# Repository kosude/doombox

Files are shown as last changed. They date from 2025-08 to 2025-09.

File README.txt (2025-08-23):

This repository contains all documentation and code for the DOOMbox Project.

My final goal for this project is an encased physical console, based on the
Pico 2 (RP2350 using Arm) dedicated to running a purpose-built DOOM clone,
maybe with a bunch of extra features thrown in for fun.

This is an evolution of my previous ambition to write a functional DOOM clone
in pure x86 assembly. The software for DOOMbox will instead be written in a
combination of C and assembly. The old project is below:

    https://gitlab.com/kosude/doom

It should be noted that Graham Saunderson has done something similar:

    https://kilograham.github.io/rp2040-doom

To be clear, DOOMbox was not inspired by RP2040 Doom, though his documentation
will probably be very helpful going forward, as I will be using similar
hardware. The main difference is that this project is more intended to just be
a fun learning experience as opposed to trying to make an authentic DOOM port
(which is why I'm not porting at all).

-------------------------[ BUILDING DOOMBOX FIRMWARE ]-------------------------

Building the firmware requires CMake, as well as the pico-sdk:

    https://github.com/raspberrypi/pico-sdk

Then (in the root project directory) configure for the desired build type:
    $ cmake . -Bbuild -DCMAKE_BUILD_TYPE=(Debug|Release)
and build:
    $ cmake --build build

Using the Debug build type enables stdio logging, which can help in debugging
(see the relevant section below).

Make sure the DBX_BUILD_FIRMWARE build option is set to ON - this is the
default value.

------------------------[ DEBUGGING DOOMBOX FIRMWARE ]-------------------------

Raspberry Pi document how to debug Pico software in one of their manuals:

    https://datasheets.raspberrypi.com/pico/getting-started-with-pico.pdf

There are multiple ways to debug, but the only properly tested route for
DOOMbox is with a second Pico, since it's the best way IMO and I don't want to
buy a "debug probe".

To go that route, GDB is required as well as Raspberry Pi's OpenOCD fork:

    https://github.com/raspberrypi/openocd

Program and set up the second Pico as shown in the Getting Started guide above
(I use the official debugprobe firmware) and then connect it to the host via
USB.

The rest of the process can be done for you by the Unified Programming and
Debugging Utility (updu.sh) in the scripts/ directory, which will by default
open a GDB session for debugging.

Reading stdout can be done in any standard way. For instance, using minicom
with a second Pico, run:

    $ minicom -b 115200 -o -D /dev/ttyACM0

(of course the device might be different)

###############################################################################

The rest of this document serves as the project's most current design
specification. Kicad schematics are also provided in the hardware/ directory.

-------------------------------[ PREREQUISITES ]-------------------------------

    ==== UNITS ====

The design specification will follow IEC 80000-13 (B: byte, b: bit):
    * 1 B   = 8 b
    * 1 kiB = 1024 B
    * 1 kB  = 1000 B
    * etc...
In all cases, use of the standard SI units indicates a decimal value, whereas
use of the IEC 80000-13 units indicates a binary value.

-----------------------------[ FILESYSTEM LAYOUT ]-----------------------------

Available capacity:
    * 4 MiB on-board flash/NVM

--------------------------------[ MEMORY MAP ]---------------------------------

TO-DO: specify memory map after reserved quantities are designated

Available memory:
    * 512 kiB on-chip SRAM
    * 2 x 4 kiB banks

Reserved memory quantities:
    * 128 kB for VGA output (320x200, 8 bpp):
        64 kB front buffer
        64 kB back buffer

----------------------------[ POWER SPECIFICATION ]----------------------------

For the time being, a simple LDO regulator is being used to step down input
voltage to 5V.

---------------------------[ GRAPHICS SPECIFICATION ]--------------------------

DOOMbox provides graphical output via VGA. Colour data is output in parallel
from the Pico directly to the VGA connector.

Colour data is output in the form RGB-332, i.e. 3 bits for the red and green
channels, and 2 for the blue.

On the Pico, GPIOs 2-9 are reserved for video data and and 10-11 for HSync and
VSync signals respectively.

When writing colour data serially, the bit-order is as follows:
    B1 B0 G2 G1 G0 R2 R1 R0
  first ---------------> last
where the leftmost bit of each channel is the MSB as usual.

Time-critical PIO machines are used for producing the synchronisation signals.
For detailed VGA timing information, see the TIMINGS.txt file in the
firmware/kernel/drivers/vga/ directory.

----------------------------[ AUDIO SPECIFICATION ]----------------------------

Stereo audio is provided via pulse width modulation (PWM). GPIOs 8 and 9 are
reserved for this purpose, where GPIO8 outputs left audio, and GPIO9 right.

    TODO better description

----------------------------[ INPUT SPECIFICATION ]----------------------------

    TODO

Required controls:
    * Move forward + move backwards | Single joystick: vertical: moving
    * Turn left + turn right        |                  horizontal: turning
    * Strafe                          Modifier btn: strafe with hoz. joystick
    * Run / speed modifier            Modifier button
    * Fire                            Button
    * Interact                        Button
    * Menu                            Button
    * Weapon selection                7 buttons

Automap necessary?

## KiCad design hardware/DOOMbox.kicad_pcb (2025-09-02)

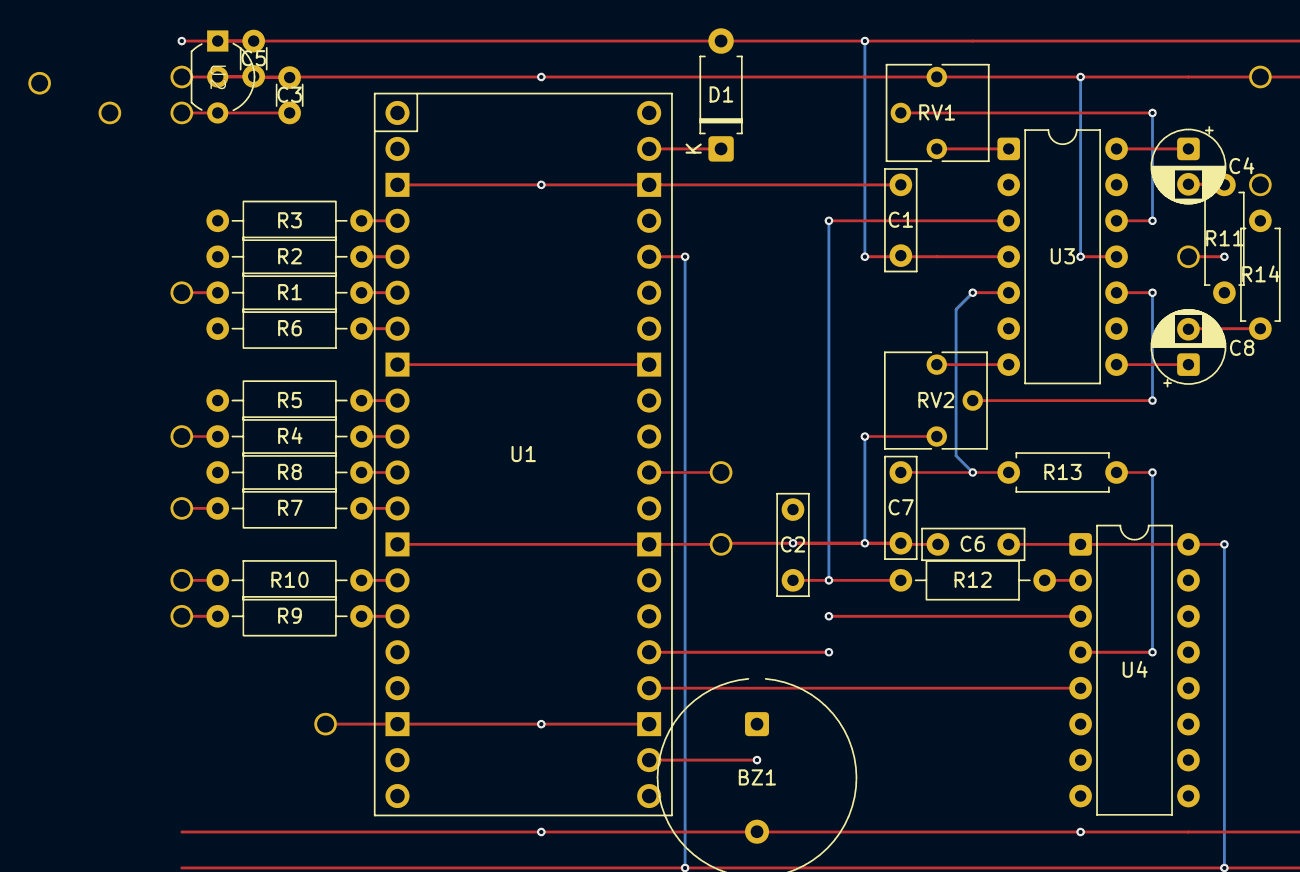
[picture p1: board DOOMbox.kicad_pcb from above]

Board: 4 copper layers, 43 parts (0 on the bottom side), 38 nets.

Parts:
BZ1: Buzzer; Indicator_PUI_AI-1440-TWT-24V-2-R
C1, C6: 100n; C_Rect_L7.0mm_W2.0mm_P5.00mm
C2, C7: 8n2; C_Rect_L7.0mm_W2.0mm_P5.00mm
C3: 1u; C_Disc_D3.0mm_W1.6mm_P2.50mm
C4, C8: 4u7; CP_Radial_D5.0mm_P2.50mm
C5: 2u2; C_Disc_D3.0mm_W1.6mm_P2.50mm
D1: D; D_A-405_P7.62mm_Horizontal
J1, J1#2, J1#3, J1#4, J1#5, J1#6: DE15_Socket_HighDensity; Peripheral_Offboard
J2, J2#2, J2#3: AudioJack3; Peripheral_Offboard
R1, R4: 499R; R_Axial_DIN0207_L6.3mm_D2.5mm_P10.16mm_Horizontal
R2, R5: 1K; R_Axial_DIN0207_L6.3mm_D2.5mm_P10.16mm_Horizontal
R3, R6: 2K; R_Axial_DIN0207_L6.3mm_D2.5mm_P10.16mm_Horizontal
R7: 412R; R_Axial_DIN0207_L6.3mm_D2.5mm_P10.16mm_Horizontal
R8, R12: 826R; R_Axial_DIN0207_L6.3mm_D2.5mm_P10.16mm_Horizontal
R9, R10: 47R; R_Axial_DIN0207_L6.3mm_D2.5mm_P10.16mm_Horizontal
R11, R14: 10K; R_Axial_DIN0207_L6.3mm_D2.5mm_P7.62mm_Horizontal
R13: 826R; R_Axial_DIN0207_L6.3mm_D2.5mm_P7.62mm_Horizontal
RV1, RV2: 100K; Potentiometer_Vishay_T73YP_Vertical
SW1, SW1#2, SW1#3: SW_SPST; Peripheral_Offboard
SW2: SW_Push; Peripheral_Offboard
U1: RPi Pico 2; RPi_Pico_SMD_TH
U2: AP7381-50SA-7; AP7381-TO92
U3: LM324N; DIP-14_W7.62mm
U4: CD4010BE; DIP-16_W7.62mm

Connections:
+3V3: C6.1, U1.36 (3V3), U4.1 (VCC), U4.16 (VDD)
+5V: C1.1, C5.1, D1.2 (A), U2.1 (VI), U3.4 (V+)
GND: BZ1.2 (-), C1.2, C2.2, C3.2, C5.2, C6.2, C7.2, J1#6.VGAGND, J2#2.S, RV1.1, RV2.1, U1.3 (GND), U1.8 (GND), U1.13 (GND), U1.18 (GND), U1.23 (GND), U1.28 (GND), U1.33 (AGND), U1.38 (GND), U2.2 (VO), U3.11 (V-), U4.8 (VSS)
HSYNC: R10.2, U1.14 (GPIO10)
unnamed: BZ1.1 (+), U1.22 (GPIO17)
unnamed: C4.2, R11.1
unnamed: C8.2, R14.1
unnamed: D1.1 (K), U1.39 (VSYS)
unnamed: J1#3.VGA1, R1.2, R2.2, R3.2
unnamed: J1#5.VGA2, R4.2, R5.2, R6.2
unnamed: J1.VGA3, R7.2, R8.2
unnamed: J1#4.VGA13, R10.1
unnamed: J1#2.VGA14, R9.1
unnamed: J2#3.R, R14.2
unnamed: J2.T, R11.2
unnamed: C3.1, SW1.1 (A), SW1#3.1 (A), U2.3 (GND)
unnamed: SW2.1, U1.30 (RUN)
unnamed: C2.1, R12.2, U3.3 (+)
unnamed: RV1.3, U3.1, U3.2 (-)
unnamed: C7.1, R13.2, U3.5 (+)
unnamed: RV2.3, U3.6 (-), U3.7
unnamed: RV2.2, U3.10 (+)
unnamed: C8.1, U3.8, U3.9 (-)
unnamed: RV1.2, U3.12 (+)
unnamed: C4.1, U3.13 (-), U3.14
unnamed: R12.1, U4.2 (G)
unnamed: R13.1, U4.4 (H)
PWM_AUL: U1.25 (GPIO19), U4.3 (A)
PWM_AUR: U1.24 (GPIO18), U4.5 (B)
VGA_B0: R8.1, U1.11 (GPIO8)
VGA_B1: R7.1, U1.12 (GPIO9)
VGA_G0: R6.1, U1.7 (GPIO5)
VGA_G1: R5.1, U1.9 (GPIO6)
VGA_G2: R4.1, U1.10 (GPIO7)
VGA_R0: R3.1, U1.4 (GPIO2)
VGA_R1: R2.1, U1.5 (GPIO3)
VGA_R2: R1.1, U1.6 (GPIO4)
VSYNC: R9.2, U1.15 (GPIO11)

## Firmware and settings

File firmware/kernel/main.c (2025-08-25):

/*
 * Copyright (c) 2025 Jack Bennett.
 * All Rights Reserved.
 *
 * See the LICENCE file for more information.
 */

#include "drivers/hal.h"
#include "drivers/vga/stress.h"
#include "drivers/vga/text/puts.h"
#include "game/init.h"
#include "kstdio.h"

int
main(void)
{
    kstdio_init(); // no-op in release config
    hal_init();

    game_main();

    return 0;
}

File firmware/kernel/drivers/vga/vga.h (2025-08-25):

/*
 * Copyright (c) 2025 Jack Bennett.
 * All Rights Reserved.
 *
 * See the LICENCE file for more information.
 */

/******************************************************************************
 * vga.h
 * Main driver interface for VGA video output via PIO and DMA.
 *****************************************************************************/

#pragma once
#ifndef __video__vga_h__
#define __video__vga_h__
#ifdef __cplusplus
extern "C" {
#endif

#include <stdint.h>

#define VGA_WIDTH       320 // the width of the used screen region
#define VGA_HEIGHT      200 // the height of the used screen region
#define VGA_SCAN_WIDTH  320 // actual width of the screen active region
#define VGA_SCAN_HEIGHT 400 // actual height of the screen active region

/**
 * VGA configuration fields.
 * GPIO field names relate directly to the respective pins on the schematic.
 */
struct vga_config {
    uint8_t gpio_b2g3r3_base; // base RGB (physically B2G3R3) GPIO
    uint8_t gpio_hsync;       // hsync pulse GPIO
    uint8_t gpio_vsync;       // vsync pulse GPIO
};

/**
 * Configure the VGA driver to drive video output on the pins specified in the
 * `op` struct.
 */
void
vga_init(const struct vga_config cfg);

#ifdef __cplusplus
}
#endif
#endif

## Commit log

2025-05-22 Kicad project init
    [DOOMbox.kicad_pcb, DOOMbox.kicad_sch]
2025-05-23 Track necessary KiCad libraries + symbols
    [DOOMbox.kicad_pcb, DOOMbox.kicad_sch]
2025-05-25 Schematic: add resistor ladder DACs for video data output
    [DOOMbox.kicad_pcb, DOOMbox.kicad_sch]
2025-07-22 Add component sheet + VGA output note in schematic
    [DOOMbox.kicad_sch, component_management.ods]
2025-07-22 Finalise VGA output schematic now w/ MCP23S08 SPI expander
    [DOOMbox.kicad_sch]
2025-07-22 More schematic changes
    [DOOMbox.kicad_sch, component_management.ods]
2025-07-23 Document inputs and storage info, and add PWM audio schematic
    [DOOMbox.kicad_sch, component_management.ods]
2025-07-24 Schem for power circuit + rpi SWD pins and reset button
    [DOOMbox.kicad_sch, component_management.ods]
2025-07-24 Clean up symbols and add footprint for MCP23S08
    [DOOMbox.kicad_sch]
2025-07-24 Rename parts sheet to bom.ods
    [bom.ods, component_management.ods]
2025-07-25 Add design for audio output w/ quad opamp + reorganise schematic
    [DOOMbox.kicad_sch]
2025-07-25 Remove BOM sheet
    [DOOMbox.kicad_sch, bom.ods]
2025-07-28 Remove outdated to-order list
    [DOOMbox.kicad_sch]
2025-07-28 README update
    [DOOMbox.kicad_sch]
2025-08-01 Rename kicad directory -> hardware/
    [DOOMbox.kicad_pcb, DOOMbox.kicad_sch]
2025-08-01 Set up CMake project for firmware (linked to pico-sdk)
2025-08-06 Add firmware_ocd.sh and gdbinit for debugging via second pico
2025-08-08 Some PWM programming and testing to play a C note
    [DOOMbox.kicad_sch]
2025-08-08 Some PWM notes added to schematic
    [DOOMbox.kicad_sch]
2025-08-08 Add GPIO for onboard speaker to current test .c src
2025-08-12 Major utility script refactor, add ocdsrv.sh for centralised management
    [ocdsrv_ports.cfg]
2025-08-15 Add starting point of the driver for the onboard buzzer
    [DOOMbox.kicad_sch]
2025-08-15 Start work on the VGA driver
2025-08-15 SPI testing for VGA (+ fix MCP address pins not tied to GND)
    [DOOMbox.kicad_sch]
2025-08-20 Working VGA output direct from Pico (ie. removed MCP23S08) + palette
    [DOOMbox.kicad_sch]
2025-08-22 Create VRAM static video memory buffer, organise VGA driver code
2025-08-23 Update README.txt: remove mention of now-unused SPI for video
2025-08-23 Rename __vgafont => __vga_font (tidy conventions)
    The vram component of the vga driver still gets its own prefix
    because typing VRAM instead of VGA_VRAM is nice
2025-08-23 Move vga driver .pio files into their own directory
2025-08-25 Draw each line twice to fix duplicated framebuffer bug
    [main.c, vga.h]
2025-08-25 VGA driver: implement VRAM double buffering
2025-08-25 Implement async "onboard" piezo speaker driver
    (also remove some unused include directives)
2025-08-25 Maybe fix double-buffering issues?
    [hal.c, vga.h]
2025-08-29 Stripboard layout WIP + custom footprints
    [DOOMbox.kicad_pcb, DOOMbox.kicad_sch]
2025-08-30 Complete stripboard design
    Squashed commit of the following:
    commit dbad1e7bdfb2dba54c7140f3a2191c6905e5781a
    Author: Jack Bennett <jackbennett0708@gmail.com>
    Date: Sat Aug 30 16:36:03 2025 +0100
    Complete
    commit 05059f46a42e6744a15d06e69ba94dfb8af3ae9c
    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
    [DOOMbox.kicad_pcb, DOOMbox.kicad_sch]
2025-08-31 Rework stripboard design (+ edit sb symbols)
    [DOOMbox.kicad_pcb, DOOMbox.kicad_sch]
2025-08-31 Shorten R12 and R13 + add missing cut
    [DOOMbox.kicad_pcb, DOOMbox.kicad_sch]
2025-08-31 Organise stripboard layers + offboard SW1
    [DOOMbox.kicad_pcb]
2025-09-02 Fix incorrect pins on U2 and accidental stripboard cut in U4
    [DOOMbox.kicad_pcb, DOOMbox.kicad_sch]
